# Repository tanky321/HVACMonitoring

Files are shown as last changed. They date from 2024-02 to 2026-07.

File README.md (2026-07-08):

# HVACMonitoring
## Know what you're doing
This project involves connections to the low-voltage AC portion of your furnace. While this is fairly straight forward, hire someone competent if you don't know what your doing.

## Background
This is an update/upgrade to my original HVAC monitoring project located here: https://github.com/tanky321/HVAC_Monitor
While that project was successful, it had a couple of drawbacks I wanted to resolve.
* Power derived from furnace. The original design was powered through the regulator on the Adafruit Huzzah32 via an external USB connection.
* The H20 detection circuit was not functional in its existing state.
* Adafruit Huzzah32 is a bit pricey. With the ability to have boards made by JLC, it made sense to go with an ESP32 Module
* Size. The old design was rather large, shrinking it down would be ideal.

## Setup
### Connections
### NOTE! THE BOARD MUST BE POWERED THROUGH THE 24VAC AND COM CONNECTIONS, THE BOARD WILL NOT POWER UP ON USB
*To be corrected in future revisions*



### ESPHome
Each assembled board is pre-flashed with the firmware in this repository when shipped. You'll need to configure the WiFi and get it hooked into Home Assistant. Setup is simple!

Once the board is powered, allow a few minutes for the fallback hotspot to be created by the device. This will take about 1 minute. 
Connect to the SSID: "HVAC Monitor Fallback Hotspot"
Password is "**pressure**"

A prompt should appear to sign into the network (on Android at least, not tested on iOS). Follow that prompt. If a prompt does not appear, navigate to [http://192.168.4.1/](http://192.168.4.1/)

A screen simillar to this one will appear. Either select your SSID, or enter it manually in the box at the bottom. Enter the appropriate password and click save


You can now navigate to [hvac-monitor.local](hvac-monitor.local) (or the assigned IP if mDNS doesn't work) to open the web interface. This will display all of the sensor readings as shown below.


Navigate back to your Home Assistant instance and then to your ESPHome instance. ESPHome will prompt that it discovered a device, click **show** and then click **Take control**


On the next window, you can modify the friendly name if needed. Once finished, click **Take control**


In Home Assistant go to **Settings -> Devices & services**, you should see a prompt to add the monitoring system as shown below. Click **Add**


Click **submit** on the following window


The **Name and assign** window will be presented, modify the Device name if required. When finished click **Skip and finish**

You will now be presented with all of the device info, and the device has been succesfully added to Home Assistant


## System Architecture
### Power
System power is derived from the AC connections to the furnace. These connections are made via the 5 position TE header on the board.
Pinout for the connector is as follows:
1. 24VAC    (Typically labeled R)
2. COMMON   (Typically labeled C)
3. HEAT     (Typically labeled W)
4. COOL     (Typically labeled Y)
5. FAN      (Typically labeled G)
   
These connections are labeled on the PCB.

The input AC is fused, rectified and fed into a 3.3V stepdown converter. A TVS diode is also included for input protection.


### Furnace State Sensors
Three opto-isolated inputs are provided to read the status of the three possible furnace states, Heat, Cool and Fan. Note that these signals are outputs from your thermostat, and inputs to your furnace. Reading of these signals is accomplished by the use of three FOD814AS optocouplers. These optocouplers contain two LEDs connected in anti-parallel, which is useful for the AC signals we're dealing with here. The transistor (emitter) output is connected to GND and the collector is connected to the ESP32 module via a pullup. Since we're dealing with an AC source, the output of the optocoupler will have brief periods where it turns off during the zero crossing portion of the AC waveform. A 10uF capacitor is used at the collector in order to smooth the ripple of the zero-crossing shutoff.


### Temperature Measurement
Temperature measurement is accomplished by three MAX6675ISA+T ICs. These ICs can only measure K-Type thermocouples (which are the most common). These sensors operate using SPI. I have typically used the three channels to measure input (return air), output (supply air) and ambient temperature. Measuring the differential temperature across the furnace + AC coil, provides a good indication of how well the furnace and AC system are working. Ambient temperature isnt really critical, just a nice data point.


### Pressure Measurement
A Sensiron SDP810-500PA sensor is used for measurement of differential pressure. This sensor uses I2C to communicate. It is capable of measuring ±2.0 inH2O (±500pA) which should be more than adequate for just about all HVAC installations. I have used magnetic static pressure probes for mechanical interface to the system. [Amazon link here](https://www.amazon.com/Dwyer-Portable-Static-Plastic-Insertion/dp/B008HOWU6I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)


### Water Detection
Two simple water detection circuits are included for detection of leaks or drain overflow. For use, connect two wires to a channels connector (J5 or J6) and place them near each other (but not touching). If water completes the circuits between the two wires, the output to the ESP32 will drive LOW, indicating a water leak detected.


## Control
Main system control/interface is done with an ESP32-C3 module. A Status LED is included and connected to GPIO3.

USB connectivity is provided for upload of firmware.



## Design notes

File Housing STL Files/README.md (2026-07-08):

# Enclosure Notes


The enclosure is designed to be 3D printed. It is not designed to be water tight by any means (there are gigantic holes in it for wires and tubing...)

The enclosure uses a light-pipe to bring the status LED to the outside of the enclosure. The light pipe is made by Bivar, and the part number is PLP5-2-1250.
They can be purchased through standard electronics distributors.

Also, note that the cover has raised text and a ring around the light pipe which can be printed in a different color if using a multi-color printer.


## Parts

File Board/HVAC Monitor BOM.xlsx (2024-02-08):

 | HVAC MONITOR BOM
 | 2024-02-07
ITEM | DESCRIPTION | MANUFACTURER | PART NUMBER | UNIT PRICE | QUANTITY | EXTENDED PRICE | REF DES | NOTE
1 | CAPACITOR, 0.1uF, 16V, 0603 | SAMSUNG | CL10B104KO8NNNC | $0.10 | 6 | $0.60 | C4, C8, C9, C10, C13, C15
2 | CAPACITOR, 0.1uF, 100V, 1206 | MURATA | GRM31C5C2A104JA01L | $0.50 | 1 | $0.50 | C3
3 | CAPACITOR, 1uF, 16V, 0603 | SAMSUNG | CL10B104KO8NNNC | $0.10 | 2 | $0.20 | C11, C16 |  | NOTE ON PRICING:
4 | CAPACITOR, 10uF, 6.3V, 0603 | SAMSUNG | CL10A106MQ8NNNC | $0.11 | 5 | $0.55 | C5, C6, C7, C12, C14 |  | PRICING HERE IS REFLECTED AS BOARD BUILD QTY 1. PARTS SOURCED FROM DIGI-KEY
5 | CAPACITOR, ALUMINUM, 47uF, 16V, SMD | PANASONIC | EEE-HC1C470P | $0.43 | 1 | $0.43 | C2
6 | CAPACITOR, ALUMINUM, 220uF, 100V | PANASONIC | EEEFK2A221AM | $2.70 | 1 | $2.70 | C1
7 | CONNECTOR, 2POS, TERM BLOCK, TH | TE | 282837-2 | $0.70 | 5 | $3.50 | J2, J3, J4, J5, J6
8 | CONNECTOR, 5POS, TERM BLOCK, TH | TE | 282837-5 | $1.56 | 1 | $1.56 | J1
9 | CONNECTOR, USB-C, R/A | AMPHENOL | 12402012E212A | $0.99 | 1 | $0.99 | J7
10 | DIODE, BRIDGE RECTIFIER, 100V, 2A, 4-SMD | CENTRAL SEMI | CBRHDSH2-100 TR13 PBFREE | $0.96 | 1 | $0.96 | D1
11 | DIODE, TVS, 58VWM, DO214AA | LITTELFUSE | SMBJ58CA | $0.37 | 1 | $0.37 | D2
12 | DIODE, TVS, 5V, SOD-523 | DIODETEC | ESD5Z3V3 | $0.10 | 3 | $0.30 | D7, D8, D9
13 | DIODE, TVS, 30V, SOD123FL | LITTELFUSE | SMF30A | $0.48 | 4 | $1.92 | D3, D4, D5, D6
14 | TRANSISTOR, NPN, 30V, SOT23-3 | ONSEMI | MMBT5089LT1G | $0.22 | 4 | $0.88 | Q1, Q2, Q3, Q4
15 | FUSE HOLDER, 5X20MM, TH | WURTH ELECTRONIK | 696108003002 | $0.68 | 1 | $0.68 | F1 | USE 696122003001 CLIP COVER
16 | IC, K-TYPE THERMOCOUPLE CONVERTER, 8-SOIC | ANALOG | MAX6675ISA+T | $16.77 | 3 | $50.31 | U1, U2, U3
17 | IC, DC-DC CONVERTER, 3.3V, 9-90V INPUT, 500mA, TH | MORNSUN | K78U03-500R3 | $2.92 | 1 | $2.92 | U4
18 | IC, OPTOISOLATOR, AC INPUT, 4-SMD | ONSEMI | FOD814AS | $0.63 | 3 | $1.89 | U5, U6, U7
19 | IC, ESP32-C3 MODULE, SMD | ESPRESSIF | ESP32-C3-WROOM-02-H4 | $2.00 | 1 | $2.00 | U8
20 | IC, USB-TO-UART BRIDGE, QFN28 | SILICON LABS | CP2102N-A02-GQFN28 | $3.53 | 1 | $3.53 | U9
21 | LED, GREEN, 0603 | KINGBRIGHT | APT2012SGC | $0.28 | 1 | $0.28 | LED1
22 | RESISTOR, 27OHM, 1/10W, 1%, 0603 | YAGEO | RC0603FR-1327RL | $0.10 | 2 | $0.20 | R22, R23
23 | RESISTOR, 200OHM, 1/10W, 1%, 0603 | YAGEO | RC0603FR-13200RL | $0.10 | 1 | $0.10 | R29
24 | RESISTOR, 1KOHM, 1/10W, 1%, 0603 | YAGEO | RC0603FR-071KL | $0.10 | 1 | $0.10 | R28
25 | RESISTOR, 2.49KOHM, 1W, 1%, 2512 | VISHAY DALE | CRCW25122K49FKEG | $0.34 | 3 | $1.02 | R3, R4, R5
26 | RESISTOR, 4.3KOHM, 1/10W,1%, 0603 | YAGEO | RC0603FR-074K3L | $0.10 | 6 | $0.60 | R1, R2, R9, R12, R13, R16
27 | RESISTOR, 5.1KOHM, 1/10W, 1%, 0603 | YAGEO | RC0603FR-135K1L | $0.10 | 2 | $0.20 | R24, R25
28 | RESISTOR, 10KOHM, 1/10W,1%, 0603 | YAGEO | RC0603FR-0710KL | $0.10 | 9 | $0.90 | R6, R7, R8, R11, R15, R17, R18, R19, R20
29 | RESISTOR, 22.1KOHM, 1/10W,1% 0603 | YAGEO | RC0603FR-1022K1L | $0.10 | 1 | $0.10 | R26
30 | RESISTOR, 47.5KOHM, 1/10W,1%, 0603 | YAGEO | RC0603FR-0747K5L | $0.10 | 1 | $0.10 | R27
31 | RESISTOR, 1MOHM, 1/10W,1%, 0603 | YAGEO | RC0603FR-071ML | $0.10 | 2 | $0.20 | R10, R14
32 | SENSOR, DIFFERENTIAL PRESSURE ±500pA, TH | SENSIRON | SDP810-500PA | 32.17 | 1 | $32.17 | SEN1
33 | SWITCH, MOMENTARY, SPST-NO, SMD | C&K | PTS820J15MSMTRLFS | 0.58 | 2 | $1.16 | S1, S2
 |  |  |  |  | TOTAL | $113.92
 | DNP | R21

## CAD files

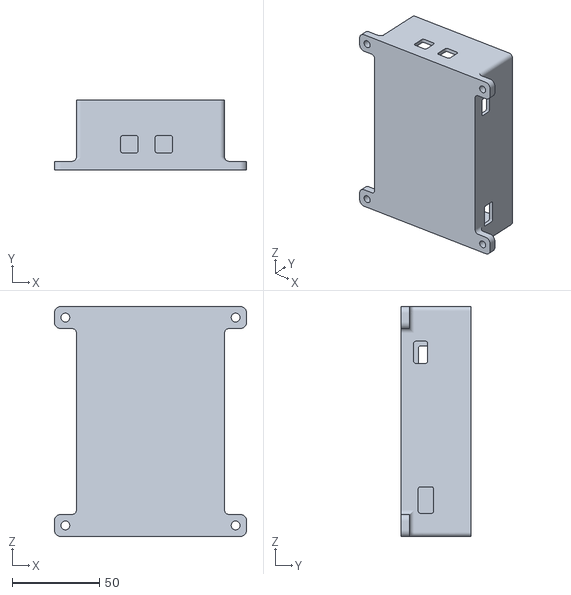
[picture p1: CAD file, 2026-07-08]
Housing STL Files/HVAC Monitor Housing.STL
110.5 x 40.3 x 132.1

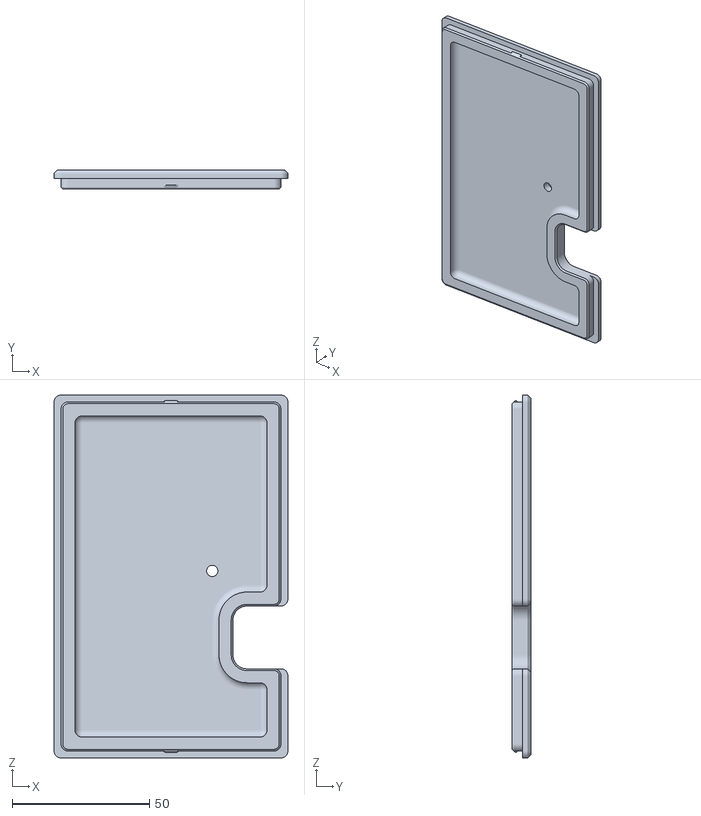
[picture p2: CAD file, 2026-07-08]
Housing STL Files/HVAC Monitor Cover.STL
85.1 x 7.01 x 132.1

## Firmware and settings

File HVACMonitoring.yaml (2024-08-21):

#Edit this for your setup
substitutions:
    name: "hvac-monitor"
    disp_name: "HVAC Monitoring System"
    update_time: 5s

esphome:
  name: "${name}"
  # Friendly names are used where appropriate in Home Assistant
  friendly_name: "${disp_name}"
  # Automatically add the mac address to the name
  # so you can use a single firmware for all devices
  name_add_mac_suffix: false
  project:
    name: "tanky321.hvac_monitoring_system"
    version: "1.0.0"
  
#Platform Setup
esp32:
  board: esp32-c3-devkitm-1
  framework:
    type: arduino #esp-idf
    version: recommended

# Enable logging
logger:

# Enable Home Assistant API
api:

#OTA Password
ota:
  - platform: esphome

# Dashboard Import
dashboard_import:
    package_import_url: github://tanky321/HVACMonitoring/HVACMonitoring.yaml@main
    import_full_config: false
    
wifi:

# Sets up Bluetooth LE (Only on ESP32) to allow the user
# to provision wifi credentials to the device.
esp32_improv:
  authorizer: none

# In combination with the `ap` this allows the user
# to provision wifi credentials to the device.
captive_portal:

#Setup simple web server to see device parameters
web_server:
  port: 80
    
#Enable SPI on GPIO18 & 19. Note that MOSI isnt needed as the max6675 just clocks out data
spi:
  clk_pin: 18
  miso_pin: 19
  interface: hardware
  
#Setup I2C for the pressure sensor on GPIO4 & 5
i2c:
  - id: bus_a
    sda: 4
    scl: 5
    scan: True

sensor:
#Monitor the wifi signal strength
  - platform: wifi_signal
    name: ${disp_name} WiFi
    update_interval: 60s

#Setup temperature sensors
  - platform: max6675
    name: "Temperature_1"
    cs_pin: 9
    update_interval: ${update_time}
  - platform: max6675
    name: "Temperature_2"
    cs_pin: 8
    update_interval: ${update_time}
  - platform: max6675
    name: "Temperature_3"
    cs_pin: 0
    update_interval: ${update_time}

#Setup pressure sensor
  - platform: sdp3x
    name: "Pressure"
    i2c_id: bus_a
    address: 0x25
    update_interval: ${update_time}
    unit_of_measurement: inH2O
    filters:
      - multiply: 0.4014630 

binary_sensor:
#Setup inputs for heat/cool/fan.
  - platform: gpio
    pin:
      number: 2
      inverted: True    #Inverted due to pcb circuit logic
      mode: INPUT
    name: "Heating"
  - platform: gpio
    pin:
      number: 1
      inverted: True
      mode: INPUT
    name: "Cooling"
  - platform: gpio
    pin:
      number: 10
      inverted: True
      mode: INPUT
    name: "Fan"
 
 #Setup inputs for water detection
  - platform: gpio
    pin:
      number: 6
      inverted: True
      mode: INPUT_PULLUP
    name: "H2O Detect #1"
  - platform: gpio
    pin:
      number: 7
      inverted: True
      mode: INPUT_PULLUP
    name: "H2O Detect #2"

#Status indicator
status_led:
  pin:
    number: 3

#Add restart functionality
switch:
  - platform: restart
    name: ${disp_name} Restart  

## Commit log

2024-01-25 Rename HVAC Monitor (PCB).pdf to Board/HVAC Monitor (PCB).pdf
2024-01-25 Rename HVAC Monitor (SCH).pdf to Board/HVAC Monitor (SCH).pdf
2024-01-25 Added board files
2024-02-08 Create HVAC Monitor BOM.xlsx
    [HVAC Monitor BOM.xlsx]
